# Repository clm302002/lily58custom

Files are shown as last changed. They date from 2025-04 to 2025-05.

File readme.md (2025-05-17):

# lily58custom

> ⚠️ **DO NOT USE THIS REPO UNLESS YOU KNOW EXACTLY WHAT YOU'RE DOING - I AM NOT RESPONSIBLE IF YOU BREAK SOMETHING**  
> This project is heavily customized for a **non-standard Lily58 layout**, and **will not work out of the box** on typical builds. It includes custom matrix changes, additional columns, and hardware-specific modifications.

---
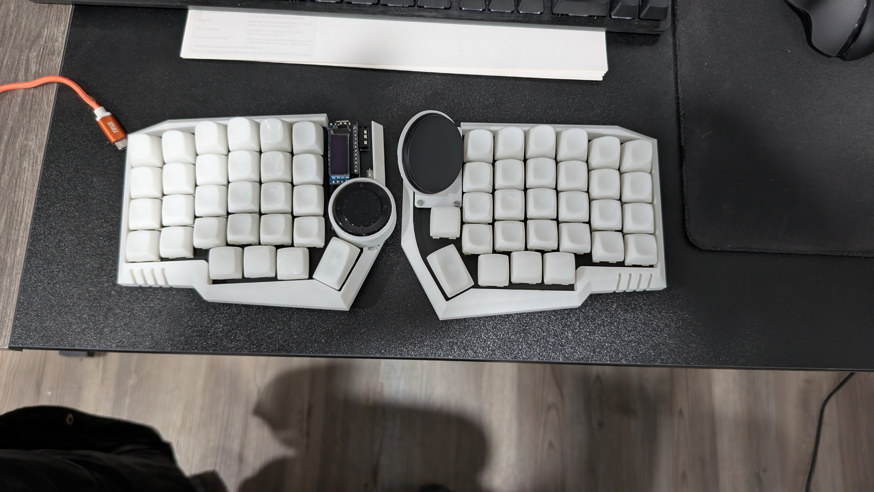
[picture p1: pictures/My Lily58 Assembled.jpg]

## Overview

This fork of the Lily58 is tailored specifically for experimental hardware mods and layout changes. It is **not compatible** with standard QMK Lily58 firmware or configurations.

### Custom Features

- **Custom column wiring** on the left half of the board for experimental key/button placement.
- Integration of the **Adafruit ANO Directional Navigation and Scroll Wheel Rotary Encoder**  
  🔗 https://www.adafruit.com/product/5001?gQT=1
- Addition of a **Cirque 40mm GlidePoint Trackpad** on the right half for cursor control.
- Dual **OLED screen support** with adjusted visibility for both halves.
- Symmetrical layout of rotary encoder and trackpad for visual balance.

---

## Case Design

- The base case design is derived from the **Capsule Deluxe** case by *Makerworld user CapsuleDeluxe*:  
  🔗 https://makerworld.com/en/models/671684-manta58-s-split-keyboard-case-for-lily58-pcbs#profileId-599425  
- I’ve modified this case to fit my custom hardware layout.  
  - My updated STL files will be added to this repo when finalized.
  - Custom parts to be included:
    - **Thick top plate**
    - **Rotary encoder mount**
    - **Cirque trackpad mount**
- For now there are other parts ive been using with some modifications, they can be found here under the original creators.
    - **[Angled 40mm Cirque](https://www.printables.com/model/409016-angled-40mm-cirque-trackpad-holder-for-lily58)**
    - **[Lily58 High-Profile Case](https://www.thingiverse.com/thing:4486280)**
    - **[DES keycaps for keyboard (Cherry MX version)](https://www.printables.com/model/865075-des-keycaps-for-keyboard-cherry-mx-version)**

## Building
This folder needs to be downloaded into your qmk_firmware/keyboards/ folder so that qmk can build it using QMK MSYS.

### Entering QMK on Arch Linux

```bash
cd ~/qmk_firmware
```
### Make example for this keyboard: using QMK MSYS, need to 

```bash
qmk compile -kb lily58custom -km test -e KEYMAP_SUFFIX=left && mv ~/qmk_firmware/.build/lily58custom_test.hex ~/qmk_firmware/.build/lily58_left.hex
qmk compile -kb lily58custom -km test -e KEYMAP_SUFFIX=right && mv ~/qmk_firmware/.build/lily58custom_test.hex ~/qmk_firmware/.build/lily58_right.hex
```
### Flashing Firmware

Once both firmware files are compiled (`lily58_left.hex` and `lily58_right.hex`), flash them to their respective halves using the Caterina bootloader (used by Pro Micro ATmega32u4 controllers).

> ⚠️ **Always flash both halves when making config changes to prevent mismatches.**

### Flash Command – Right Half

```bash
qmk flash ~/qmk_firmware/.build/lily58_right.hex --bootloader caterina
qmk flash ~/qmk_firmware/.build/lily58_left.hex --bootloader caterina
```

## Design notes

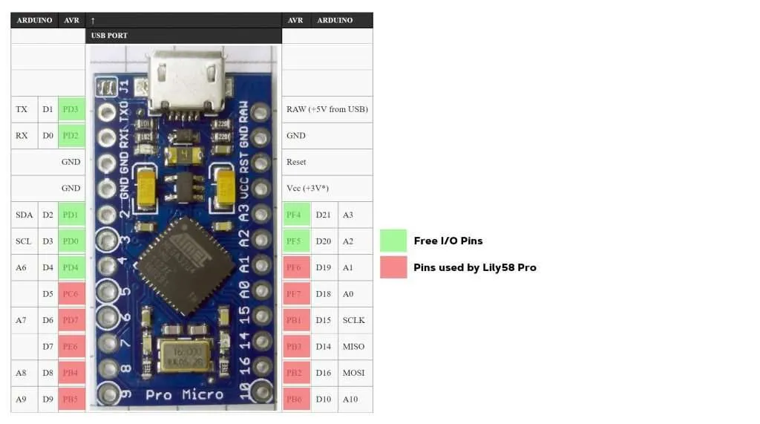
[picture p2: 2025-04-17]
pictures/Pro-Micro-Pinout-used-by-Lily58-Pro-1024x571.webp

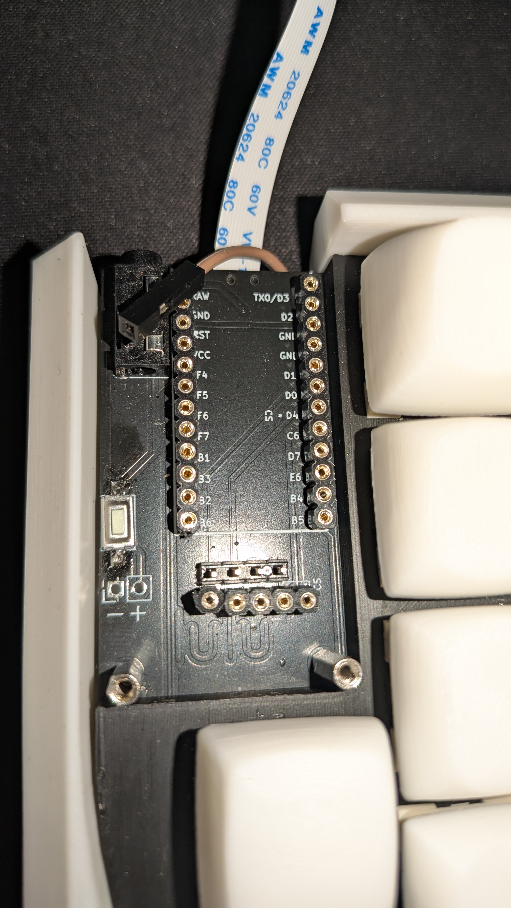
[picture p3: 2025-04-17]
pictures/Right Side Top.jpg

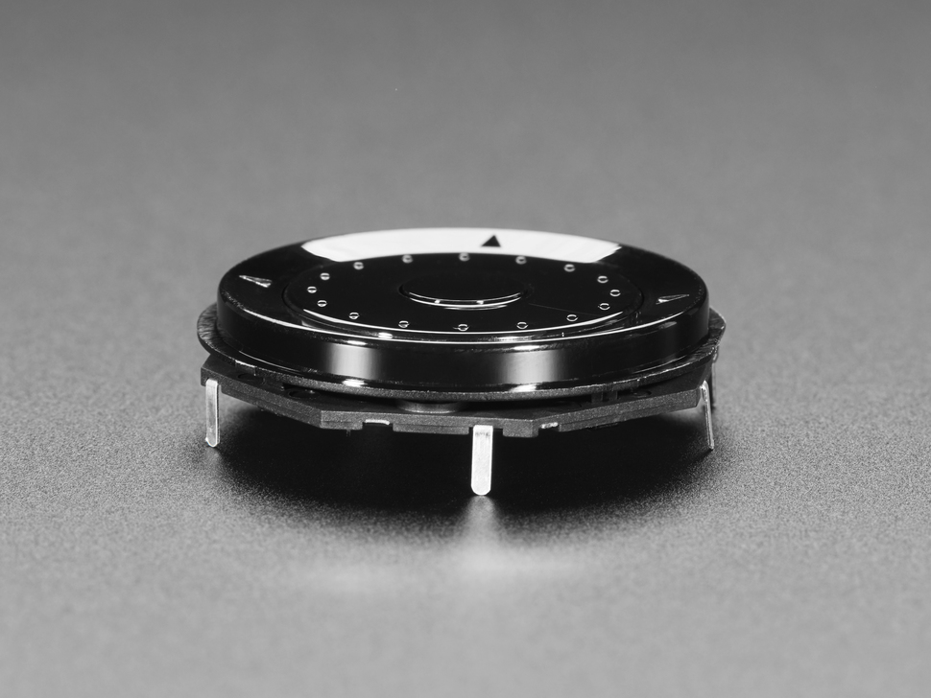
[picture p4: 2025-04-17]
pictures/ANO Directional Navigation and Scroll Wheel Rotary Encoder 4.jpg

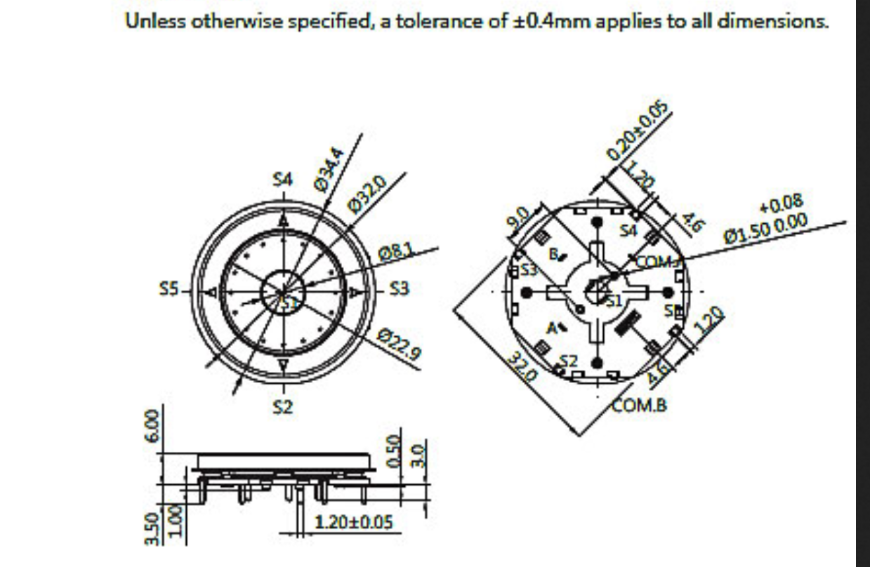
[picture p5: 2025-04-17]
pictures/adafruit dimensions top.png

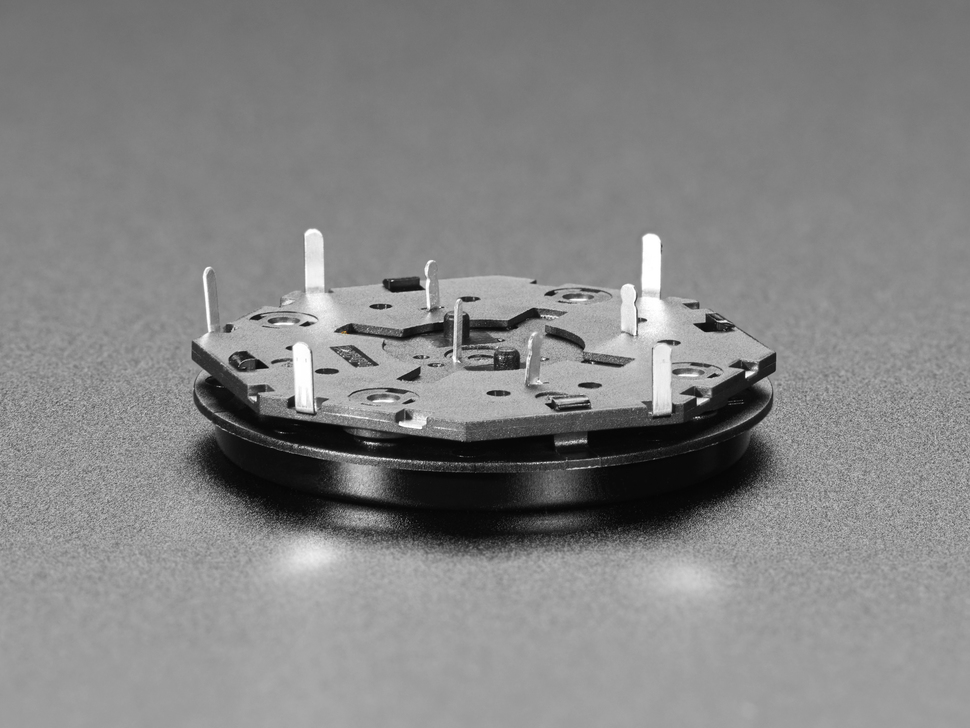
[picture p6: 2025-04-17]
pictures/ANO Directional Navigation and Scroll Wheel Rotary Encoder 1.jpg

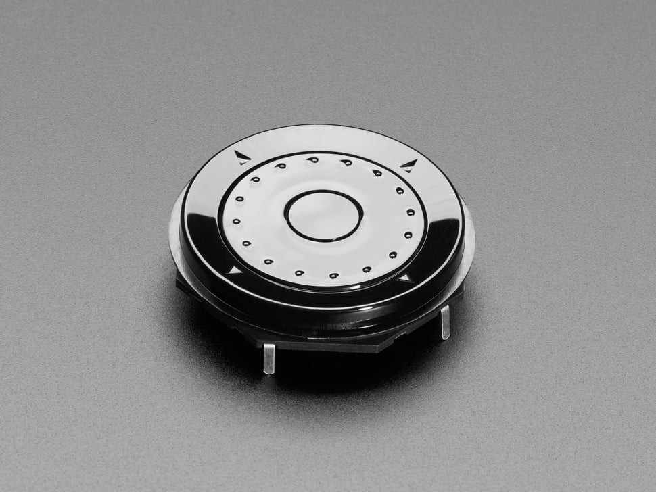
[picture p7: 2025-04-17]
pictures/ANO Directional Navigation and Scroll Wheel Rotary Encoder 3.jpg

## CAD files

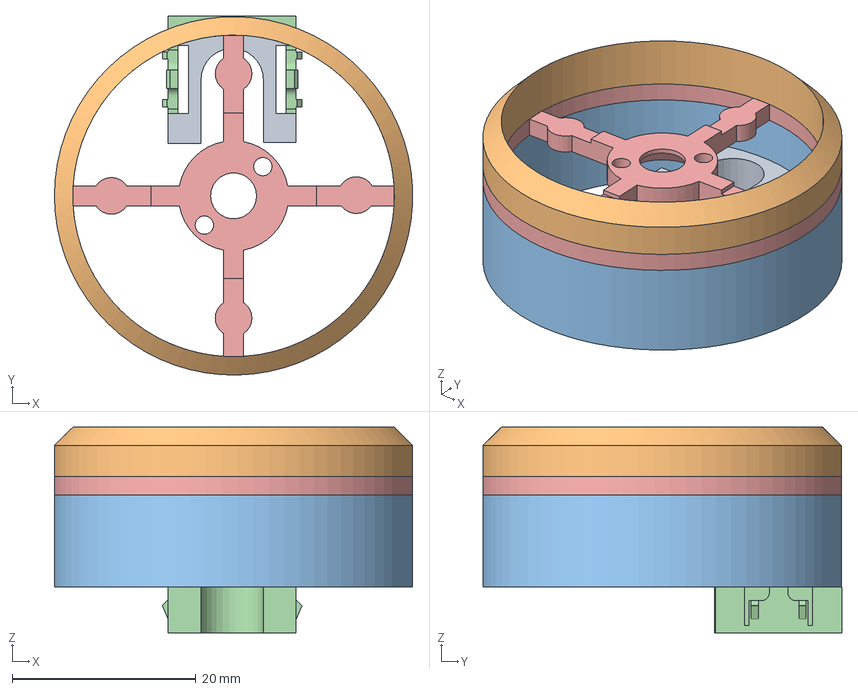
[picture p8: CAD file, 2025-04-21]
STLFiles/encoder v12 tall.3mf
39.0 x 39.1 x 22.4 mm
Mount Base
Skirt
Switch Plug Bottom
Top Lid

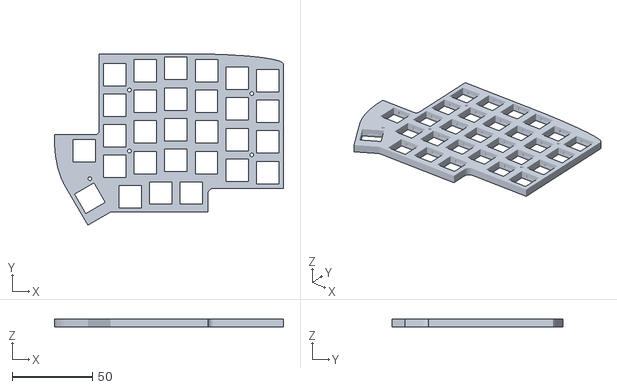
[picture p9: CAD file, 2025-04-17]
STLFiles/lily58 top plate thick (best).stl
142.6 x 106.6 x 5.00

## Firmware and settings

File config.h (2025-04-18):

#pragma once

#define DYNAMIC_KEYMAP_LAYER_COUNT 4
#define TAPPING_TERM 100
#define QUICK_TAP_TERM 0
#define MASTER_RIGHT

#ifdef VIA_ENABLE
#    define VIA_KEYBOARD_UID {0xB4, 0x19, 0x77, 0x63, 0xAC, 0xE2, 0x01, 0x4D}
#endif

#ifdef RGB_MATRIX_ENABLE
#    define RGB_MATRIX_LED_COUNT 29        // total number of all LEDs chained together
#    define DRIVER_LED_TOTAL 29
#    define RGB_DI_PIN D3                  // update if you're using another pin
#    define RGB_MATRIX_MAXIMUM_BRIGHTNESS 120
#    define RGB_MATRIX_DEFAULT_VAL 120     // sets 50% brightness on boot
#    define RGB_MATRIX_DEFAULT_MODE RGB_MATRIX_SOLID_COLOR
#    define RGB_MATRIX_DEFAULT_HUE 0
#    define RGB_MATRIX_DEFAULT_SAT 255
#    define RGB_DISABLE_AFTER_TIMEOUT 0    // stay on always
#    define RGB_MATRIX_KEYPRESSES          // optional: effects react to keypresses
#    define RGB_MATRIX_FRAMEBUFFER_EFFECTS // optional: additional animated effects
#endif

#ifdef RGBLIGHT_ENABLE
#    define RGBLIGHT_DEFAULT_MODE RGBLIGHT_MODE_STATIC_LIGHT
#    define RGBLIGHT_DEFAULT_COLOR 0xFFFFFF
#    define RGBLIGHT_LIMIT_VAL 120
#    define RGBLIGHT_HUE_STEP 10
#    define RGBLIGHT_SAT_STEP 17
#    define RGBLIGHT_VAL_STEP 17
#endif

// ------------------------
// ========== LEFT ==========
// ------------------------
#if defined(KEYMAP_SUFFIX_left)
#    define ENCODER_A_PINS { F4 }
#    define ENCODER_B_PINS { F5 }
// Mute button on D3 (direct pin) - TAKEN BY RGB?!??!?!
//#    define DIRECT_PINS { { D3 } }
#endif

// ------------------------
// ========== RIGHT ==========
// ------------------------
#if defined(KEYMAP_SUFFIX_right)
// Cirque Trackpad configuration
#    define SPLIT_POINTING_ENABLE  // Enable split support for pointing devices
#    define POINTING_DEVICE_RIGHT  // The Cirque is on the right (master) side
#    define I2C1_SDA_PIN D1        // I2C data pin
#    define I2C1_SCL_PIN D0        // I2C clock pin
#    define CIRQUE_PINNACLE_I2C_ADDRESS 0x2A  // Default I2C address for Cirque Pinnacle
#    define CIRQUE_PINNACLE_DIAMETER_MM 40   // Set to your trackpad's diameter in mm
#    define CIRQUE_PINNACLE_TAP_ENABLE       // Enable tap-to-click support
#    define POINTING_DEVICE_GESTURES_SCROLL_ENABLE  // Enable circular scroll gesture
//#    define POINTING_DEVICE_ROTATION_90      // Rotate input 90° CW to correct mounting orientation
// #    define POINTING_DEVICE_ROTATION_180   // Uncomment if mounted upside-down (180°)
#    define POINTING_DEVICE_ROTATION_270   // Uncomment for 90° CCW
#    define CIRQUE_PINNACLE_DIAGONAL_SENSITIVITY 64  // Increase diagonal responsiveness (0–127)
#    define CIRQUE_PINNACLE_DRAG_LOCK true   // Enable drag-lock (tap-and-hold to drag)
#    define CIRQUE_PINNACLE_Z_IDLE_COUNTS 10 // Lower idle counts for faster tap detection
#    define CIRQUE_PINNACLE_SENSITIVITY 0x0F // Overall sensitivity (0x00–0x7F)
#    define POINTING_DEVICE_TASK_THROTTLE_MS 1  // Increase report rate (lower is faster updates)
#endif

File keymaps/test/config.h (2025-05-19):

/*
 * Copyright 2025 Nanomed
 *
 * This program is free software: you can redistribute it and/or modify
 * it under the terms of the GNU General Public License as published by
 * the Free Software Foundation, either version 2 of the License, or
 * (at your option) any later version.
 */

#pragma once

// ───────────────────────────────
// 🧠 Core Settings
// ───────────────────────────────
#define MASTER_RIGHT                // USB plugged into right side
#define NO_SUSPEND_POWER_DOWN
#define USE_SERIAL                  // Split connection via TRRS
//#define USE_I2C                   // Uncomment if using I2C instead

// ───────────────────────────────
// 🖥️ OLED Display Settings
// ───────────────────────────────
#define OLED_DISPLAY_128X32
#define OLED_TIMEOUT 0             // Never turn off
#define OLED_BRIGHTNESS 128

#define SPLIT_OLED_ENABLE
//#define SPLIT_LAYER_STATE_ENABLE
//#define SPLIT_MODS_ENABLE
//#define SPLIT_LED_STATE_ENABLE
//#define SPLIT_WPM_ENABLE
#define SPLIT_TRANSPORT_MIRROR

// ───────────────────────────────
// 🎛️ Encoder Support
// ───────────────────────────────
#define ENCODER_A_PINS { F4 }
#define ENCODER_B_PINS { F5 }
#define SPLIT_ENCODERS_ENABLE

// ───────────────────────────────
// 🎨 RGB Matrix Settings (if enabled)
// ───────────────────────────────
#ifdef RGB_MATRIX_ENABLE
#    define RGB_MATRIX_LED_COUNT 74
#    define DRIVER_LED_TOTAL 74
#    define RGB_DI_PIN D3
#    define RGB_MATRIX_MAXIMUM_BRIGHTNESS 120
#    define RGB_MATRIX_DEFAULT_VAL 120
#    define RGB_MATRIX_DEFAULT_MODE RGB_MATRIX_SOLID_COLOR
#    define RGB_MATRIX_DEFAULT_HUE 0
#    define RGB_MATRIX_DEFAULT_SAT 255
#    define RGB_DISABLE_AFTER_TIMEOUT 0
#    define RGB_MATRIX_KEYPRESSES
#    define RGB_MATRIX_FRAMEBUFFER_EFFECTS
#endif

// ───────────────────────────────
// 🌈 RGB Light Settings (if enabled)
// ───────────────────────────────
#ifdef RGBLIGHT_ENABLE
//#    define RGBLED_NUM 72              //this was added in the keyboard.json
//#    define RGBLIGHT_LED_COUNT RGBLED_NUM     //this was added in the keyboard.json  
#    define RGBLED_SPLIT { 36, 36 }
#    define RGBLIGHT_LIMIT_VAL 120
#    define RGBLIGHT_HUE_STEP 1
#    define RGBLIGHT_SAT_STEP 17
#    define RGBLIGHT_VAL_STEP 17
#    define RGBLIGHT_DEFAULT_MODE RGBLIGHT_MODE_STATIC_LIGHT
#    define RGBLIGHT_DEFAULT_COLOR 0xFFFFFF
#endif

// ───────────────────────────────
// 🖱️ Trackpad (Cirque) – Only on RIGHT side
// ───────────────────────────────
#if defined(KEYMAP_SUFFIX_right)
#    define SPLIT_POINTING_ENABLE
#    define POINTING_DEVICE_RIGHT
#    define I2C1_SDA_PIN D1
#    define I2C1_SCL_PIN D0
#    define CIRQUE_PINNACLE_I2C_ADDRESS 0x2A
#    define CIRQUE_PINNACLE_DIAMETER_MM 40
#    define CIRQUE_PINNACLE_TAP_ENABLE
//#    define CIRQUE_PINNACLE_DRAG_LOCK true
//#    define POINTING_DEVICE_GESTURES_SCROLL_ENABLE
#    define POINTING_DEVICE_ROTATION_270
#    define CIRQUE_PINNACLE_DIAGONAL_SENSITIVITY 64
#    define CIRQUE_PINNACLE_Z_IDLE_COUNTS 10
#    define CIRQUE_PINNACLE_SENSITIVITY 0x0C
#    define CIRQUE_PINNACLE_ATTENUATION EXTREG__TRACK_ADCCONFIG__ADC_ATTENUATE_2X
#    define POINTING_DEVICE_TASK_THROTTLE_MS 1
#endif

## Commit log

2025-04-17 added 3d files
    [lily58 top plate thick (best).stl]
2025-04-20 Right half flipped still
    [config.h, keymap.c]
2025-04-21 removed layout, rotated right matrix numbers. keys still reversed
    [config.h, keymap.c]
2025-04-21 reversed row pins, SOLVED THE KEYMAP!
    [keymap.c]
2025-04-21 via file setup, not working
    [config.h, keymap.c]
2025-04-21 fixed using default keymap. need to fix via, encoder too
    [config.h, keymap.c]
2025-04-22 trying to get encoder to controll both sets of lights
2025-05-15 fixed rgb split, updated readme
    [encoder v12 tall.3mf, lily58 top plate thick (best).stl]
